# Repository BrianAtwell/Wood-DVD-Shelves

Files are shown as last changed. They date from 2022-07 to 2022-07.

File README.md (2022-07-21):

# Wood-DVD-Shelves
I made some Shelves in FreeCAD to fit the space at the bottom of my stairs. It uses common square edge boards except a few custom width pieces. The bottom is deeper to improve stability. The shelves are 8" between shelves to fit DVD/blueray and custom cases. They also feature a vent at the bottom for floor vents.

There are two shelves, a short and a tall one.

## Tall Shelf
The tall shelf has seven shelves each 2' 10" wide. The overall dimensions are 2' 11" wide by 5' 5+3/4" high.

### Perspective View
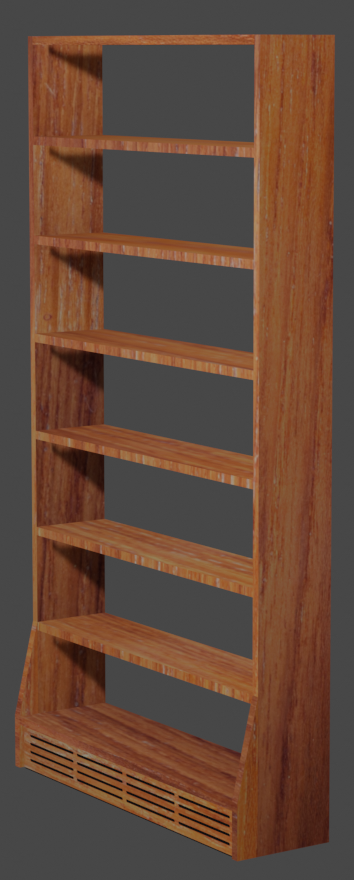
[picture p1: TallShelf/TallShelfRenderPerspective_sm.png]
Tall DVD Shelf Perpective view


### Assembly View
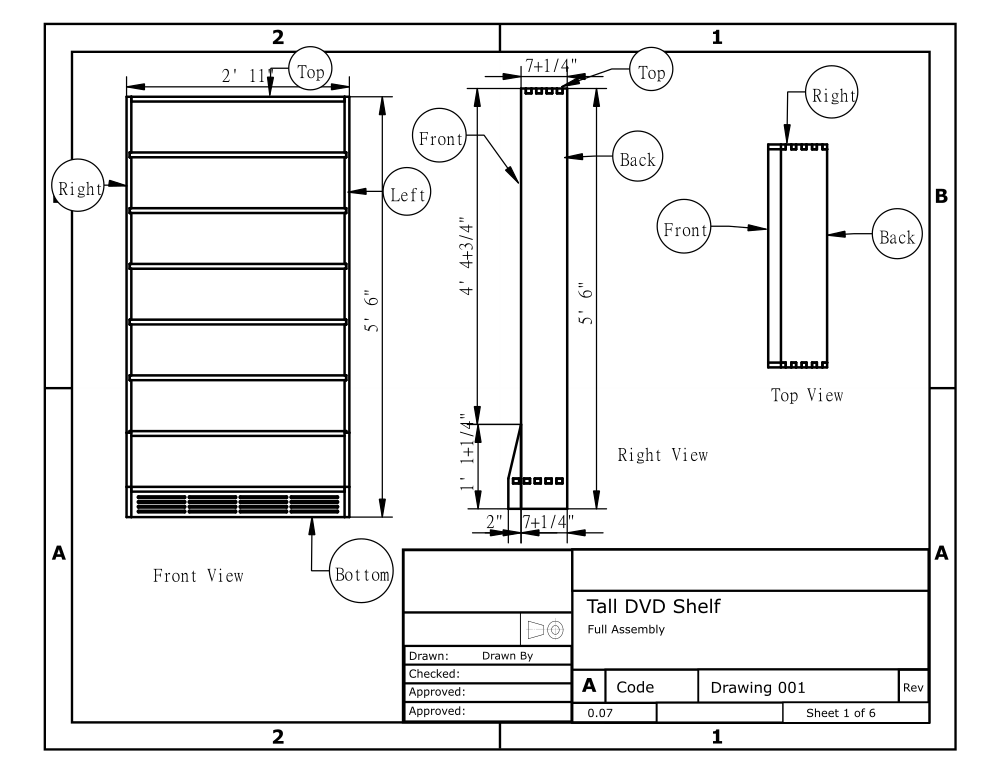
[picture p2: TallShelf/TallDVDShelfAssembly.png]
Tall DVD Shelf Assembly


## Short Shelf
The short shelf has four shelves each 3' 5" wide. The overall dimensions are 3' 6+1/2" wide by 3' 3+3/4" high.

### Perspective View
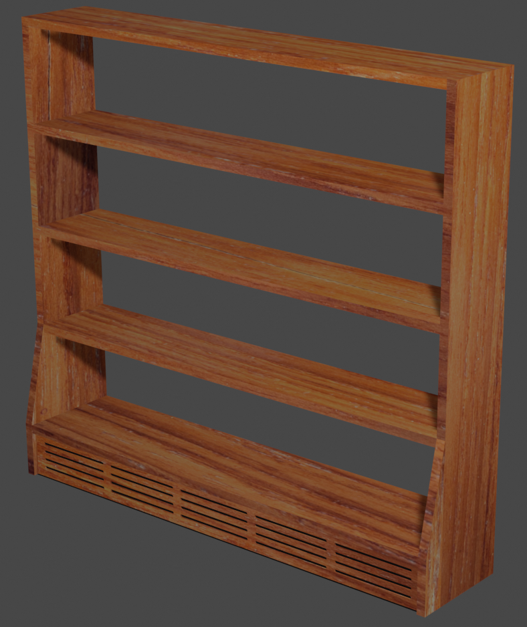
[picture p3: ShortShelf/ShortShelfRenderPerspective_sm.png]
Short DVD Shelf Perpective view


### Assembly View
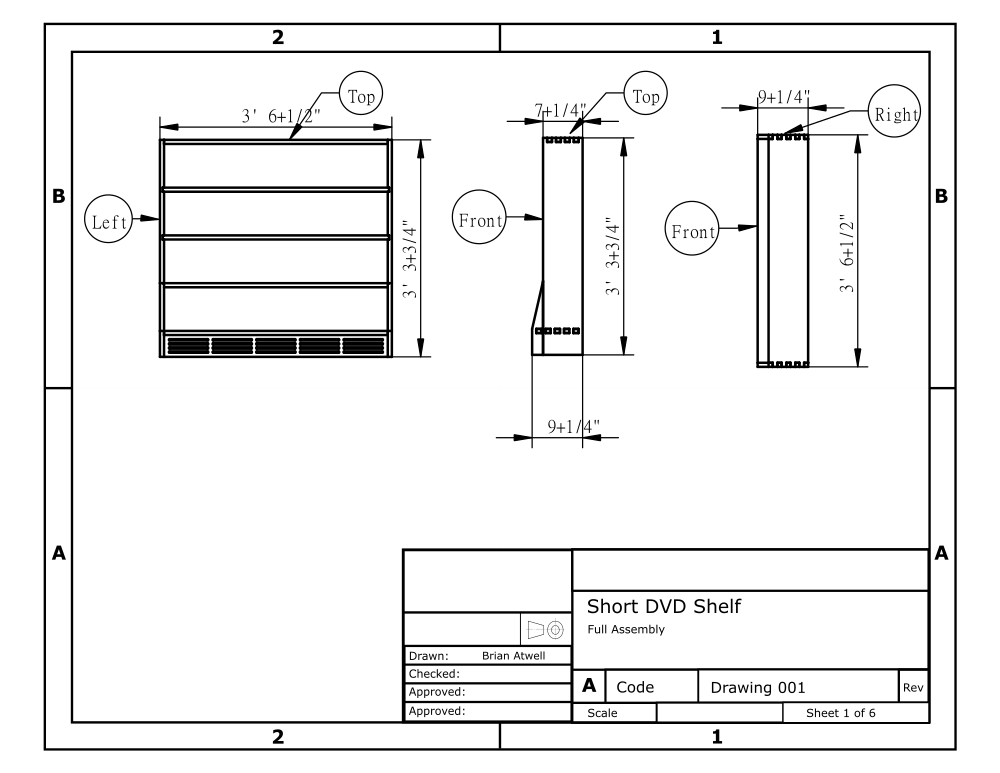
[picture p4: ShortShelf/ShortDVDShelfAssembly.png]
Short DVD Shelf Assembly


# Both Shelves
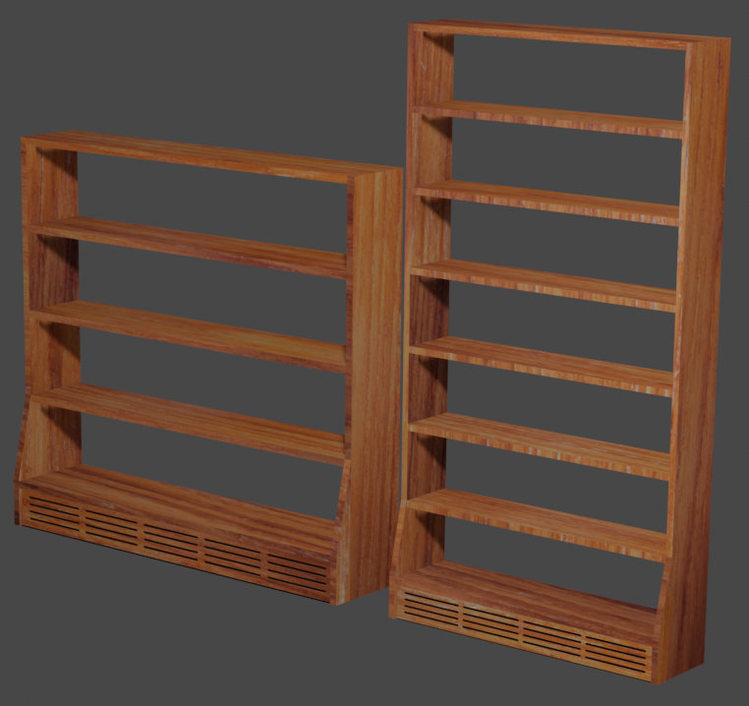
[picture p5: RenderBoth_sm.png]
Both Shelves Assembly


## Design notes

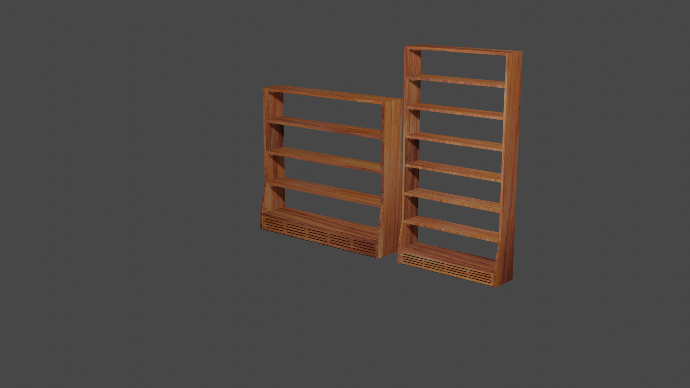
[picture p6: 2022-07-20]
RenderBoth.png

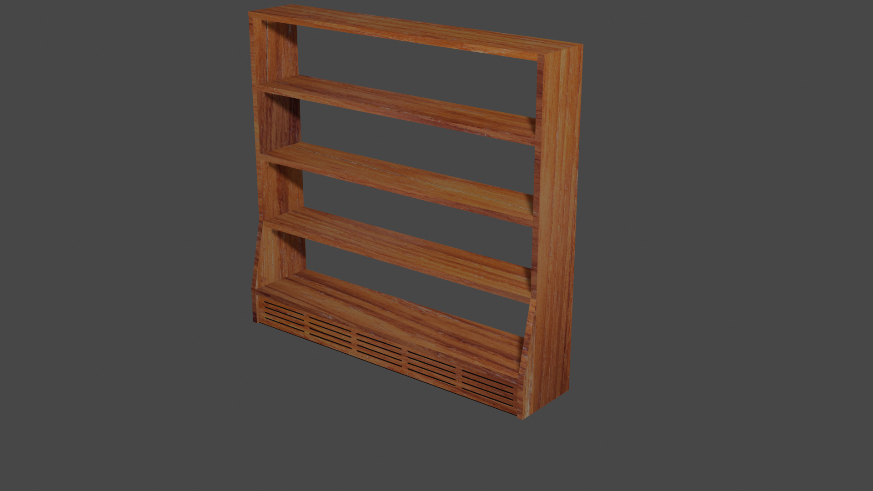
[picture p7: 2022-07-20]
ShortShelf/ShortShelfRenderPerspective.png

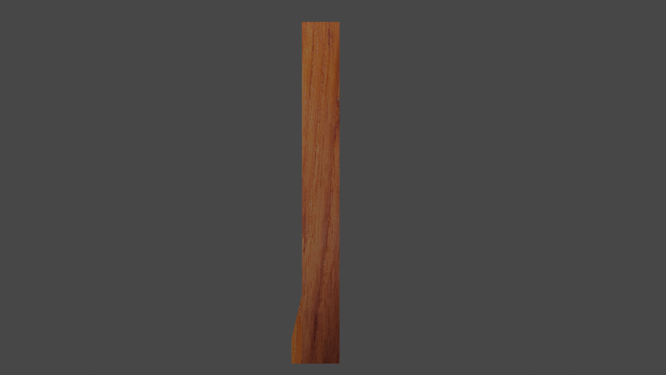
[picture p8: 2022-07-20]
TallShelf/TallShelfRenderSide.png

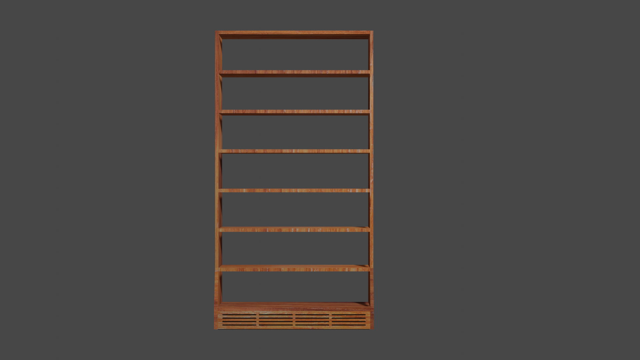
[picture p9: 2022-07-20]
TallShelf/TallShelfRenderFront.png

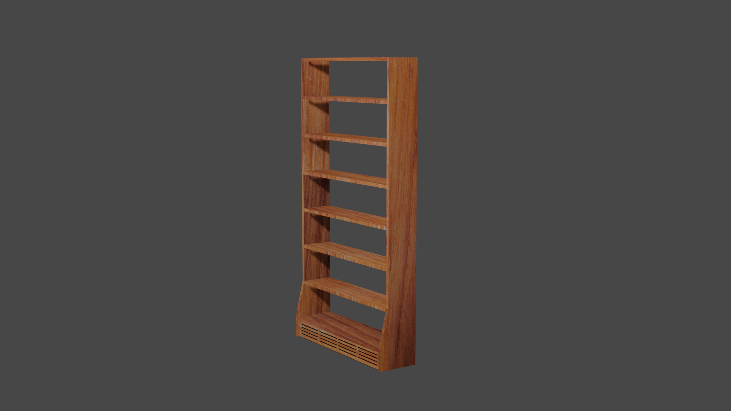
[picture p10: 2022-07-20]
TallShelf/TallShelfRenderPerspective.png

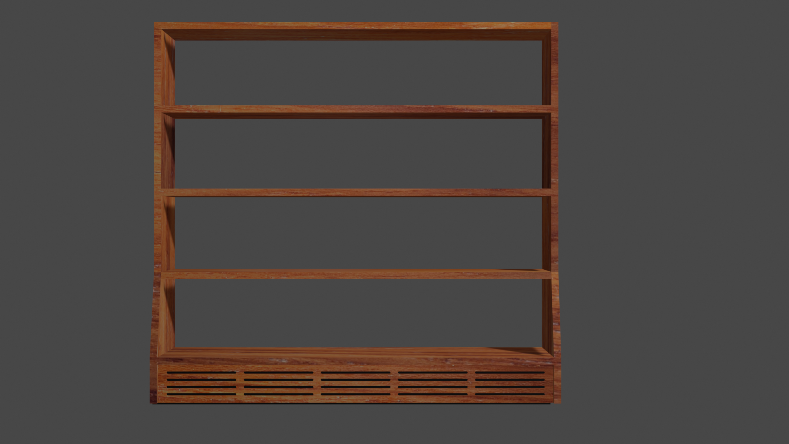
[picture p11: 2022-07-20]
ShortShelf/ShortShelfRenderFront.png

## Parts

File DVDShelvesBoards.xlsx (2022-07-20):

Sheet: ShortShelf
ShortShelf
File: | ShortShelfV13
Board | $13.00 | 1 in. x 8 in. x 8 ft
Board | $14.20 | 1 in. x 10 in. x 8 ft.
 |  |  |  | Board
Part | Length | Length Inches | Width | 10in Width | 8in Width
BackDeadSpace | 3' 5" | 41" | 4" | 0.25
FrontDeadSpace | 3' 5" | 41" | 4" | 0.25
Shelves | 3' 5 1/2" | 41.5" | 7.25 |  | 3
BottomShelf | 3' 6 1/2" | 42.5" | 7.25 | 1
TopShelf | 3' 6 1/2" | 42.5" | 7.25 |  | 1
LeftSide | 3' 3 1/2" | 39.5" | 7.25 |  | 1
RighSide | 3' 3 1/2" | 39.5" | 7.25 |  | 1
 |  |  |  | 1.5 | 3
Board Type | # Boards |  | Partial | Whole
8in Width | 3 |  | $39.00 | $39.00
10in Width | 1.5 |  | $21.30 | $28.40
 |  | Total | $60.30 | $67.40

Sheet: TallShelf
TallShelf
File: | TallShelfV10-TechView
Board | $13.00 | 1 in. x 8 in. x 8 ft
Board | $8.20 | 1 in. x 8 in. x 6 ft
Board | $14.20 | 1 in. x 10 in. x 8 ft.
 |  |  |  | Board
Part | Length | Length Inches | Width | 10in Width | 8in Width x 6ft | 8in Width x 8ft
BackDeadSpace | 2' 9 1/2" | 33.5" | 4" | 0.25
FrontDeadSpace | 2' 9 1/2" | 33.5" | 4" | 0.25
Shelves | 2' 10" | 34" | 7.25 |  |  | 6
BottomShelf | 2' 11" | 35" | 7.25 | 1
TopShelf | 2' 11" | 35" | 7.25 |  |  | 1
LeftSide | 5' 5 3/4" | 65.75" | 7.25 |  | 1
RighSide | 5' 5 3/4" | 65.75" | 7.25 |  | 1
 |  |  |  | 1.5 | 2 | 3.5
Board Type | # Boards |  | Partial | Whole
8in Width x 8ft | 3.5 |  | $28.70 | $32.80
8in Width x 6ft | 2 |  | $28.40 | $28.40
10in Width | 1.5 |  | $21.30 | $28.40
 |  | Total | $78.40 | $89.60

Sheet: Sheet3
Combined
Board Type | Cost |  | URL
1 in. x 8 in. x 8 ft | $13.00 | Aisle 17 Bay 006 | https://www.homedepot.com/p/1-in-x-8-in-x-8-ft-Premium-Kiln-Dried-Square-Edge-Whitewood-Common-Board-914835/100065210
1 in. x 8 in. x 6 ft | $8.20 | Aisle 17 Bay 006 | https://www.homedepot.com/p/1-in-x-8-in-x-6-ft-Premium-Kiln-Dried-Square-Edge-Whitewood-Common-Board-914827/100085326
1 in. x 10 in. x 8 ft. | $14.20 | Aisle 17 Bay 006 | https://www.homedepot.com/p/1-in-x-10-in-x-8-ft-Premium-Kiln-Dried-Square-Edge-Whitewood-Common-Board-914908/100069358
Board Type | # Boards |  | Partial | Whole | Whole Boards
8in Width x 8ft | 6.5 |  | $84.50 | $91.00 | 7
8in Width x 6ft | 2 |  | $16.40 | $16.40 | 2
10in Width | 3 |  | $42.60 | $42.60 | 3
 |  | Total | $143.50 | $150.00

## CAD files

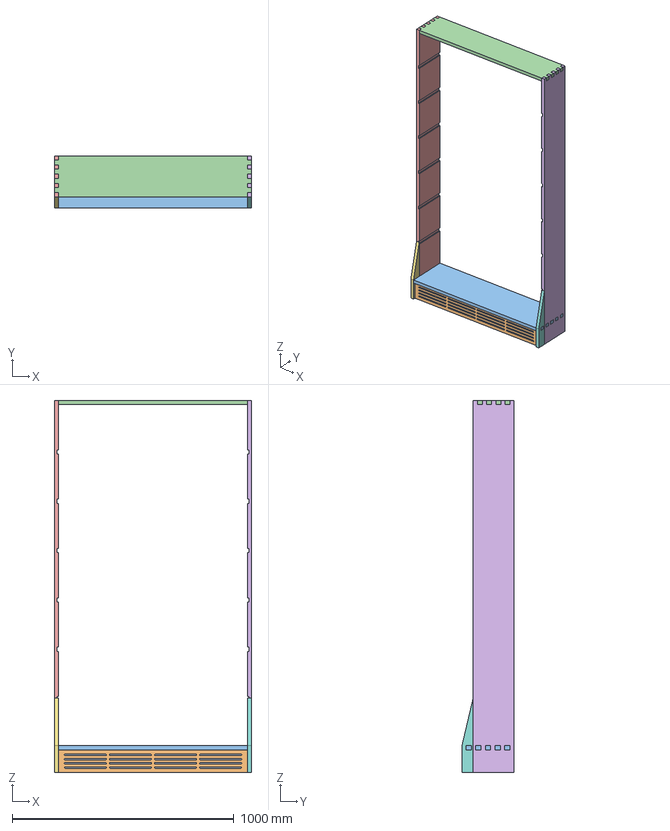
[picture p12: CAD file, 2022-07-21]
TallShelf/TallShelfV12.FCStd
889.0 x 235.0 x 1676.4 mm
BackDeadSpaceBoard
FrontDeadSpaceBoardCut
BottomShelfBoardFinal
TopShelfBoardFinal
LeftSideBoardFinal
RightSideBoardFinal
LeftSideScapFinal
RightSideCapFinal

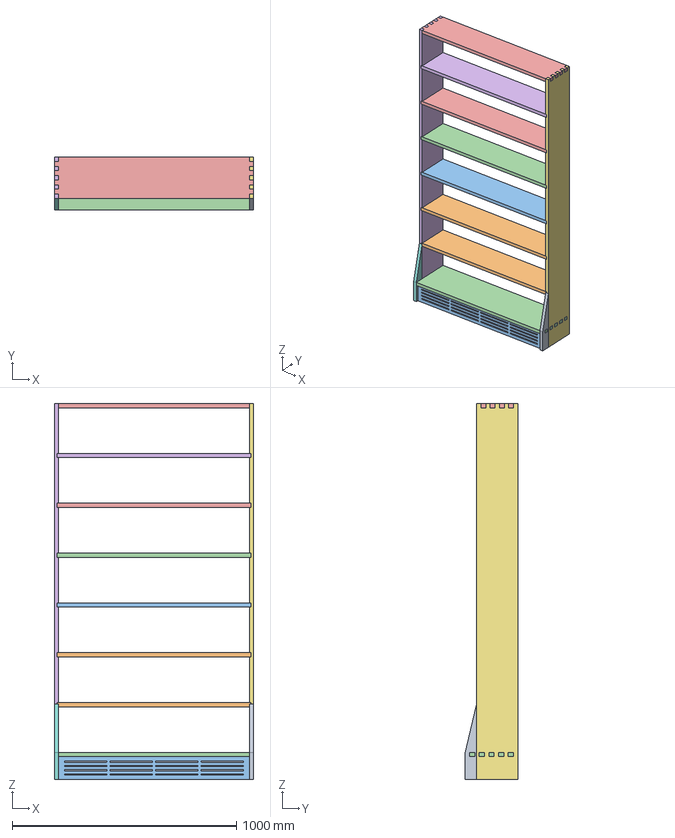
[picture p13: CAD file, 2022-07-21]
TallShelf/TallShelfV12-TechViewV2.FCStd
889.0 x 235.0 x 1676.4 mm
BackDeadSpaceBoard
SecondShelfBoard
FrontDeadSpaceBoardCut
BottomShelfBoardFinal
TopShelfBoardFinal
LeftSideBoardFinal
RightSideBoardFinal
LeftSideScapFinal
RightSideCapFinal
ThirdShelfBoaard
FourthShelfBoard
FifthShelfBoard
SixShelfBoard
SeventhShelfBoard

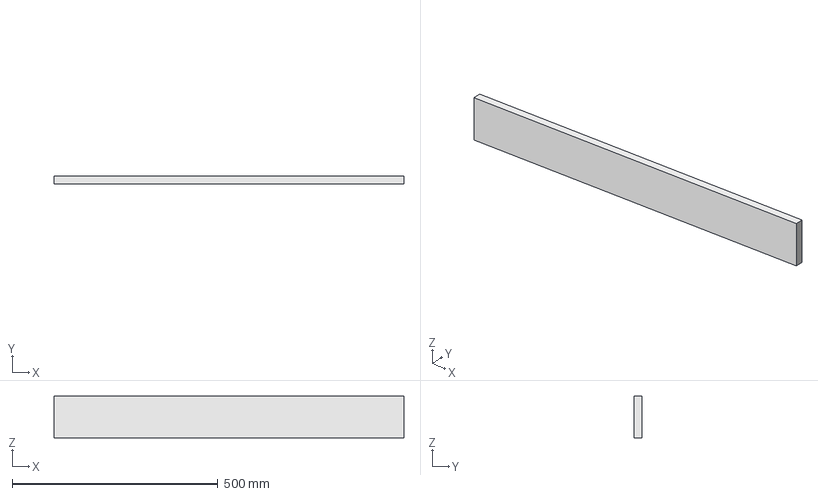
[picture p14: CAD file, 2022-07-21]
TallShelf/TallShelfV12-TechViewV3.FCStd
850.9 x 19.1 x 101.6 mm

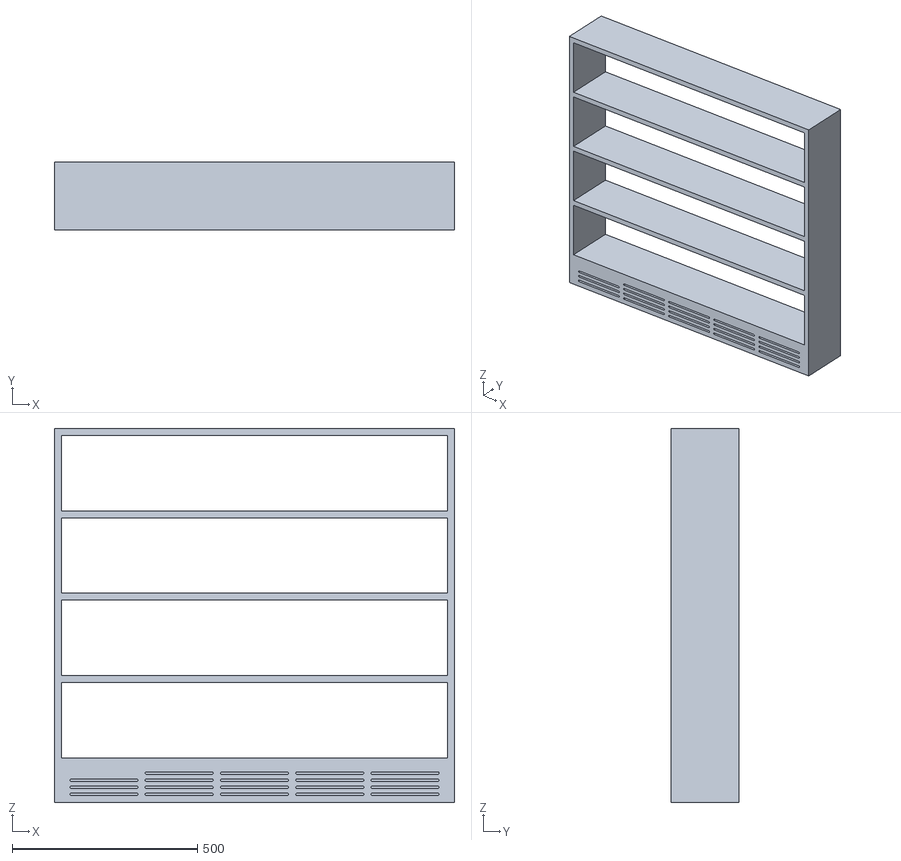
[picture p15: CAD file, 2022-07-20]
ShortShelf/ShortShelfV6-Compound (blender).obj
1079.5 x 184.1 x 1009.7

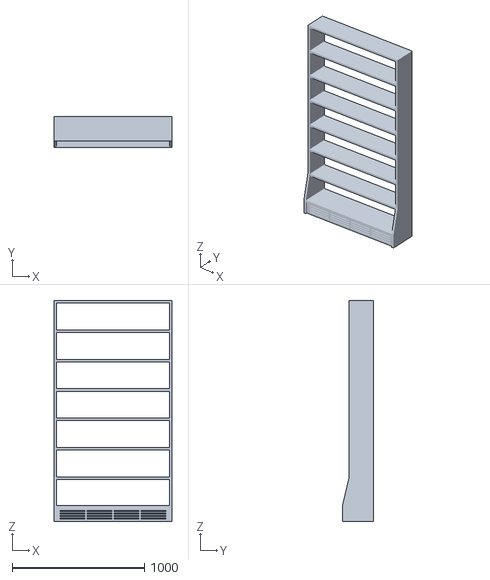
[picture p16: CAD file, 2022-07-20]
TallShelf/TallShelfV10-TechViewV5-Compound.obj
889.0 x 234.9 x 1670.1

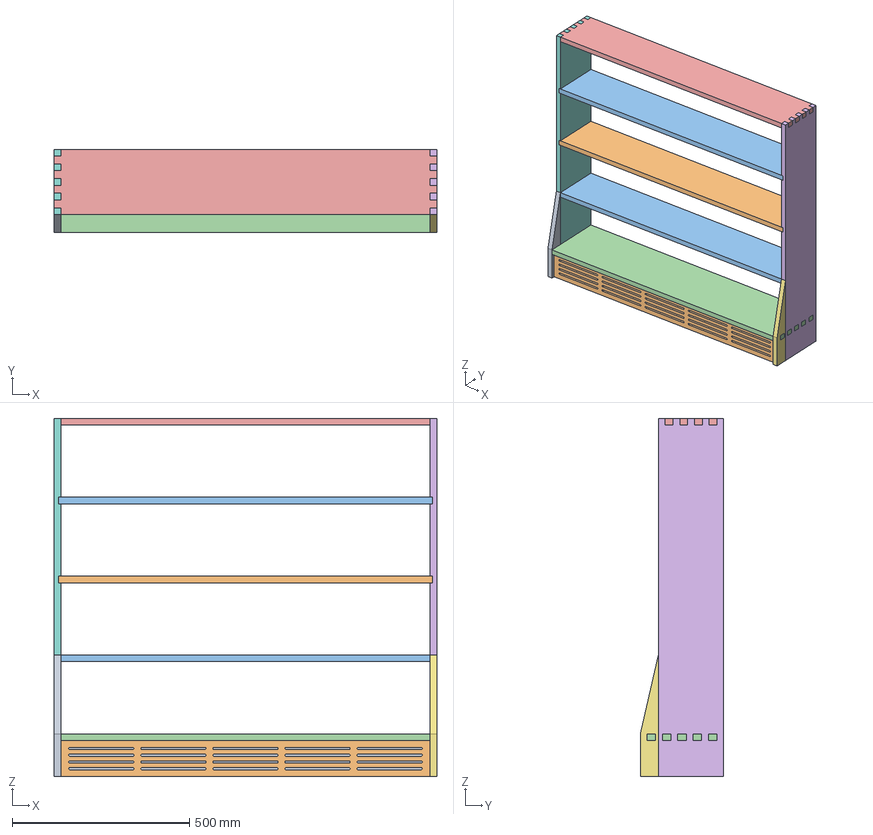
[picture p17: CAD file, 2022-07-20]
ShortShelf/ShortShelfV17-TechviewV1.FCStd
1079.5 x 235.0 x 1009.7 mm
BottomBackDeadSpace
FrontDeadSpaceCut
SecondShelfBoard
FirstShelfCut001
TopShelfCut001
RightSideBoard001
RightSideBoardScap
LeftSideBoard001
LeftSideBoardScap
ThirdShelfBoard
FourthShelfBoard

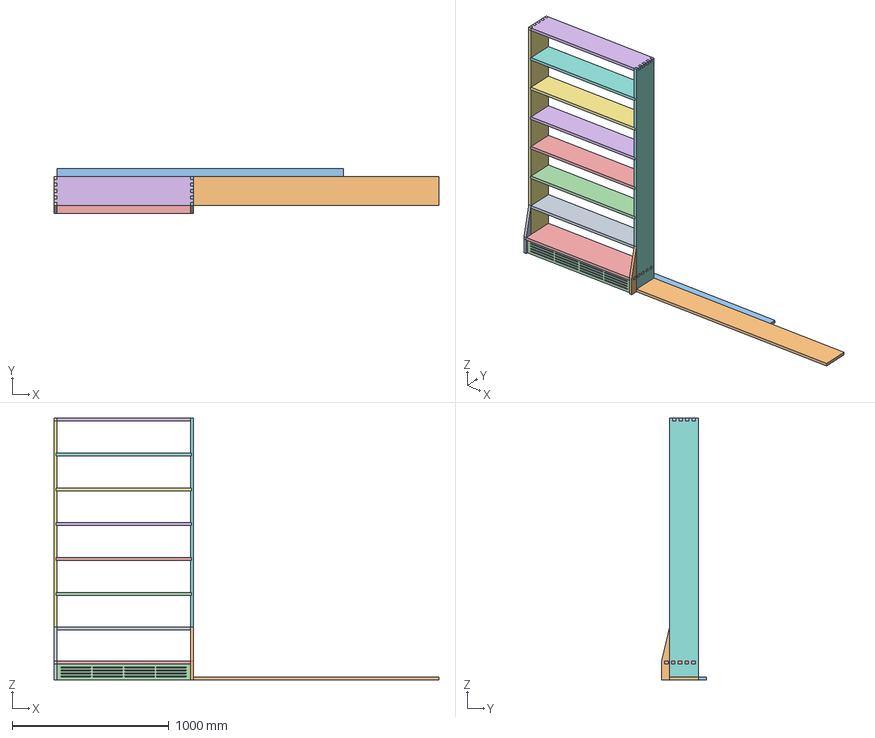
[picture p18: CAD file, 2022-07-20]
TallShelf/TallShelfV10-TechView.FCStd
2457.5 x 285.8 x 1670.0 mm
WoodBoard 1in x 8in x 8ft
WoodBoard 1in x 10in x 6ft
BackDeadSpaceBoard
SecondShelfBoard
SecondShelfBoard001
SecondShelfBoard002
SecondShelfBoard003
SecondShelfBoard004
FrontDeadSpaceBoard
FirstShelf
EightShelf
LeftSideBoard
RightSideBoard
LeftSideScap
RightSideScap
SecondShelf
ThirdShelf
FourthShelf
FifthShelf
SixthShelf
SeventhShelf

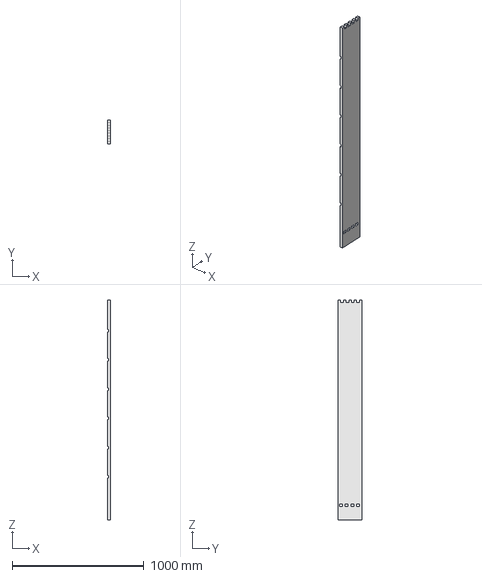
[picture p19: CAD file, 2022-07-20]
TallShelf/TallShelfV10-TechViewV4.FCStd
19.0 x 184.2 x 1670.0 mm

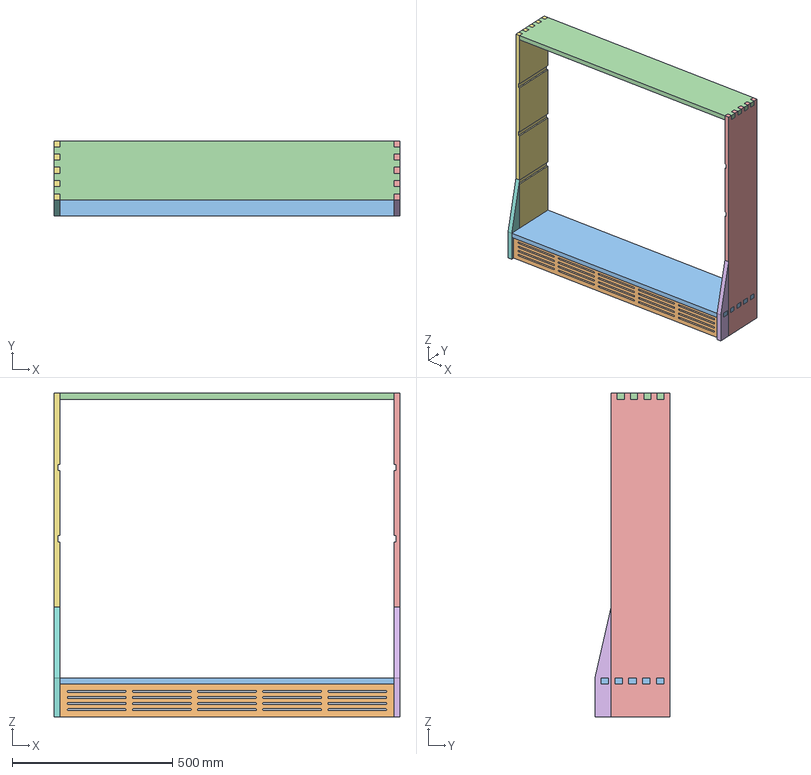
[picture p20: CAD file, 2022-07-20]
ShortShelf/ShortShelfV17.FCStd
1079.5 x 235.0 x 1009.7 mm
BottomBackDeadSpace
FrontDeadSpaceCut
FirstShelfCut001
TopShelfCut001
RightSideBoard001
RightSideBoardScap
LeftSideBoard001
LeftSideBoardScap

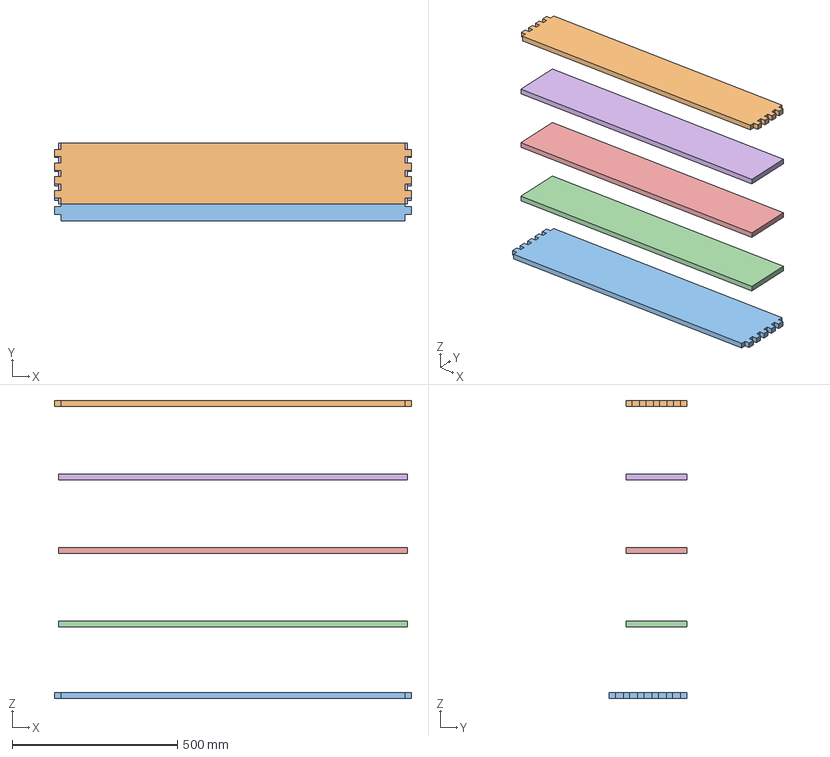
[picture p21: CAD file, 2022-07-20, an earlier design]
ShortShelf/ShortShelfV16-TechviewV1.FCStd
1079.5 x 235.0 x 901.7 mm
SecondShelfBoard002
TopShelfCut003
FirstShelfCut003
SecondShelfBoard005
ThirdShelfBoard
FourthShelfBoard

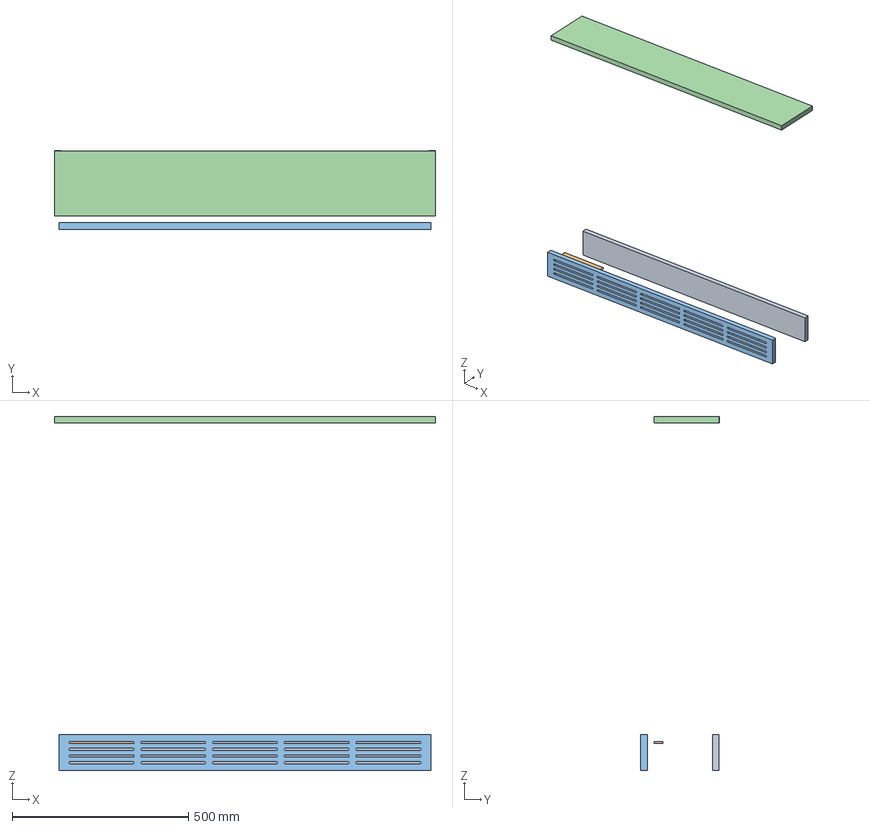
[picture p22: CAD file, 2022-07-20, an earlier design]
ShortShelf/ShortShelfV11.FCStd
1079.5 x 222.8 x 1003.3 mm
BottomBackDeadSpace
FrontDeadSpaceCut
TopShelfBoard

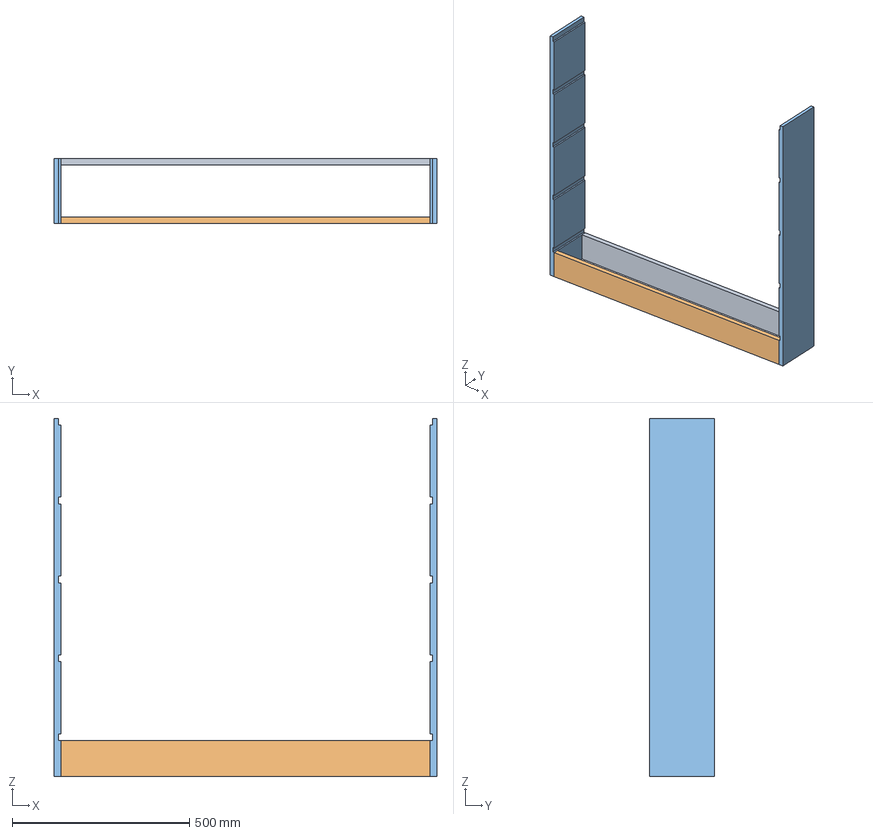
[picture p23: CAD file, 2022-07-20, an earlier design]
ShortShelf/ShortShelfV4.FCStd
1079.5 x 184.2 x 1009.7 mm
BottomBackDeadSpace
FrontBackDeadSpace

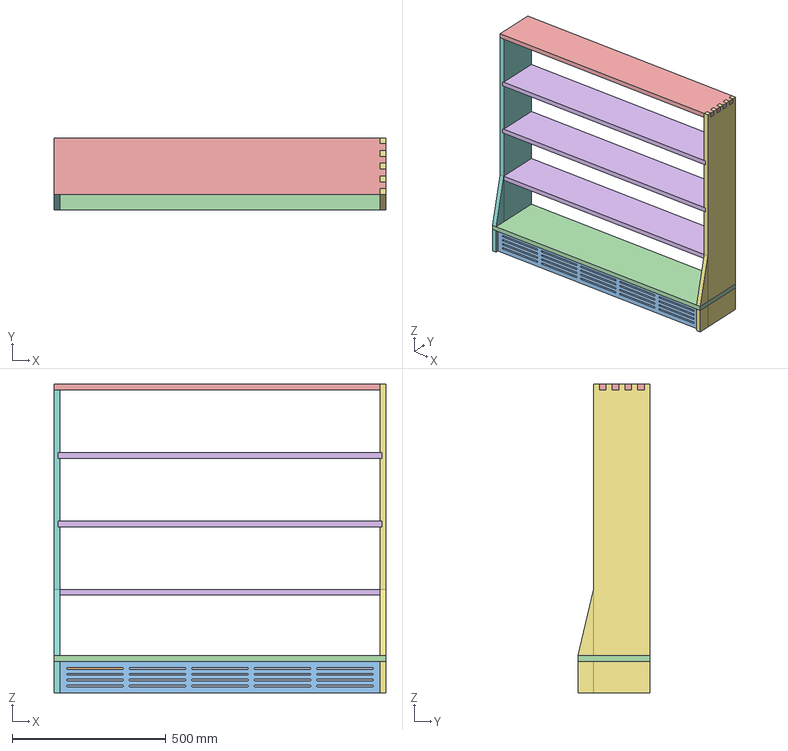
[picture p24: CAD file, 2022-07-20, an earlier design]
ShortShelf/ShortShelfV13.FCStd
1079.5 x 235.0 x 1003.3 mm
BottomBackDeadSpace
FrontDeadSpaceCut
FirstShelfBoard002
TopShelfBoard
RightSideFinalCut
LeftSideFinalCut

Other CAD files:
TallShelf/TallShelfV12-TechViewV1.FCStd
ShortShelf/ShortShelfV17-TechviewV1-Compound.obj
TallShelf/TallShelfV10-TechViewV5.FCStd
ShortShelf/ShortShelfV9.FCStd
TallShelf/TallShelfV11.FCStd
BlenderRender.blend
ShortShelf/ShortShelfV1.FCStd
ShortShelf/ShortShelfV10.FCStd
ShortShelf/ShortShelfV12.FCStd
ShortShelf/ShortShelfV14.FCStd
ShortShelf/ShortShelfV15-TechviewV1.FCStd
ShortShelf/ShortShelfV15.FCStd
ShortShelf/ShortShelfV2.FCStd
ShortShelf/ShortShelfV3.FCStd
ShortShelf/ShortShelfV5.FCStd
ShortShelf/ShortShelfV6.FCStd
ShortShelf/ShortShelfV7.FCStd
ShortShelf/ShortShelfV8.FCStd
TallShelf/TallShelfV1.FCStd
TallShelf/TallShelfV10-TechViewV2.FCStd
TallShelf/TallShelfV10-TechViewV3.FCStd
TallShelf/TallShelfV10.FCStd
TallShelf/TallShelfV2.FCStd
TallShelf/TallShelfV3.FCStd
TallShelf/TallShelfV4.FCStd
TallShelf/TallShelfV5.FCStd
TallShelf/TallShelfV6.FCStd
TallShelf/TallShelfV7.FCStd
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
